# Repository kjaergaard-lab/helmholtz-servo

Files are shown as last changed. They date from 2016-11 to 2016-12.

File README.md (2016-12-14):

# Helmholtz Servo

The design contained here is an analogue PID controller, with some
peculiarities specific for controlling the current though the
Helmholtz coil of our apparatus.

## Status
This project is not yet in production use.

## Where to look

This repository contains the KiCad project for the controller. PDF
copies of the schematic, PCB, and documentation can be found in the
*Generated* folder.

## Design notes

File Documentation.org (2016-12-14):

* Purpose
  This device is intended to be used to regulate the current through a
  Helmholtz coil, used for generating a magnetic field in our cold
  atom collider.

  The majority of the system is built from chopper-stabilized
  amplifiers, for their very low input bias, and DC performance. This
  limits the bandwidth of the filter, and can cause aliasing. Hence
  this controller is not designed for "fast" systems.

  This schematic is for documentation purposes only.

* Signals
Only HH_TTL is isolated, and with the optional exception of the SENSE
input, all other grounds/shields are shared.
** HH_TTL
   The Helmholtz TTL signal switches on or off the output voltage. In
   our case, the control voltage is being used to drive MOSFETs, so
   these are turned off. 
   
   The Integrator is also reset with this signal, preventing accumulation
   while the servo is not active from causing transient behaviour when
   the servo is enabled.

   The polarity of this signal is set by populating certain resistors
   (R9-12, R5, R6) as per the schematic.
   
   This signal is opto-isolated, so may operate at a relative potential
   to the rest of this circuit. The signal is assumed to be 5V, and
   will cause about 10 mA current draw.

** V_REF
   This is the output of a 5 V voltage reference, for use with an
   external DAC.
** V_DAC
   This is assumed to be the output of the DAC, and is used as the
   set-point for the PID controller
** SENSE
   This is the Process Variable, as a current signal. The current
   is passed through a precision 1 ohm resistor, and the resulting
   voltage is compared to V_DAC to generate the error signal.

   The current return is optionally connected to ground by bridging R1.
** OUT
   This is the Control Variable, which is the result of the PID
   operation on the error.

* Configuration
  HH_TTL has selectable polarity by selecting which resistors to
  populate on the analog switches the signal activates. (R9-12, R5,
  R6).

  The SENSE shield can optionally be grounded by putting a 0 ohm
  resistor (or solder bridge) in R1.

  The total polarity of the system is selected using JP1 and
  JP2. These should both be loaded with jumpers between pins 1 and 2
  for the default, non-inverting operation. They should be swapped to
  pins 2 and 3 to invert the output. *NB:* Either remove both jumpers
  first, or make sure device is unpowered with no inputs before
  changing the polarity. This is to ensure that two inputs are not
  shorted together while configuring. Note that during operation, the
  jumpers should be connecting the same pin numbers, but will be
  positioned at physically opposite ends of the jumpers.

* Power
  This board is designed to be powered off a dual supply. If a
  negative supply is not available, the negative supply pin may be grounded,
  and positive operation will be available.

* Erata
** TC7650
   These amplifiers are only capable of a 18 V supply, but the
   specified dual 15 V supplies give supply of 30 V. The circuit can
   be used with +/- 8 V supplies instead of +/- 15 V with these
   amplifiers.

   These amplifiers have been replaced with the LTC1150, which can
   handle these supply ranges, but has a much lower bandwidth. These
   devices were chosen as they are available in a DIP package, and
   could be placed on the existing board, when removing all the
   switching capacitors (C16, C15, C27, C26, C22, C21, C32, C31, C36, C35,
   C40, C41).

** RV6 - Output Gain
   This resistor was wired with pins 1 and 2 reversed in the
   2016-11-14 board. These must be swapped for correct operation.

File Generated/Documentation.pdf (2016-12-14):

### Documentation

December 15, 2016

## Contents

1 Purpose | 1
2 Signals | 2
3 Conguration | 3
4 Power | 3
5 Erata | 3
1 | Purpose

This device is intended to be used to regulate the current through a Helmholtz coil, used for generating a magnetic eld in our cold atom collider.
| The majority of the system is built from chopper-stabilized ampliers, for
their very low input bias, and DC performance. This limits the bandwidth of the lter, and can cause aliasing. Hence this controller is not designed for "fast" systems.
| This schematic is for documentation purposes only.

1

## 2 Signals

Only HHTTL is isolated, and with the optional exception of the SENSE input, all other grounds/shields are shared.

2.1 HHTTL

The Helmholtz TTL signal switches on or o the output voltage. In our case, the control voltage is being used to drive MOSFETs, so these are turned o. The Integrator is also reset with this signal, preventing accumulation while the servo is not active from causing transient behaviour when the servo is enabled.
The polarity of this signal is set by populating certain resistors (R9-12, R5, R6) as per the schematic.
This signal is opto-isolated, so may operate at a relative potential to the rest of this circuit. The signal is assumed to be 5V, and will cause about 10 mA current draw.

2.2 VREF

This is the output of a 5 V voltage reference, for use with an external DAC.

2.3 VDAC

This is assumed to be the output of the DAC, and is used as the set-point for the PID controller

2.4 SENSE

This is the Process Variable, as a current signal. The current is passed through a precision 1 ohm resistor, and the resulting voltage is compared to VDAC to generate the error signal.
The current return is optionally connected to ground by bridging R1.

2.5 OUT

This is the Control Variable, which is the result of the PID operation on the error.

2

## 3 Conguration

HHTTL has selectable polarity by selecting which resistors to populate on the analog switches the signal activates. (R9-12, R5, R6).
The SENSE shield can optionally be grounded by putting a 0 ohm resistor (or solder bridge) in R1.
The total polarity of the system is selected using JP1 and JP2. These should both be loaded with jumpers between pins 1 and 2 for the default, non-inverting operation. They should be swapped to pins 2 and 3 to invert the output. NB: Either remove both jumpers rst, or make sure device is unpowered with no inputs before changing the polarity. This is to ensure that two inputs are not shorted together while conguring. Note that during operation, the jumpers should be connecting the same pin numbers, but will be positioned at physically opposite ends of the jumpers.

## 4 Power

This board is designed to be powered o a dual supply. If a negative supply is not available, the negative supply pin may be grounded, and positive operation will be available.

5 | Erata
5.1 | TC7650

These ampliers are only capable of a 18 V supply, but the specied dual 15 V supplies give supply of 30 V. The circuit can be used with +/- 8 V supplies instead of +/- 15 V with these ampliers.
These ampliers have been replaced with the LTC1150, which can handle these supply ranges, but has a much lower bandwidth. These devices were chosen as they are available in a DIP package, and could be placed on the existing board, when removing all the switching capacitors (C16, C15, C27, C26, C22, C21, C32, C31, C36, C35, C40, C41).

5.2 RV6 - Output Gain

This resistor was wired with pins 1 and 2 reversed in the 2016-11-14 board. These must be swapped for correct operation.

3

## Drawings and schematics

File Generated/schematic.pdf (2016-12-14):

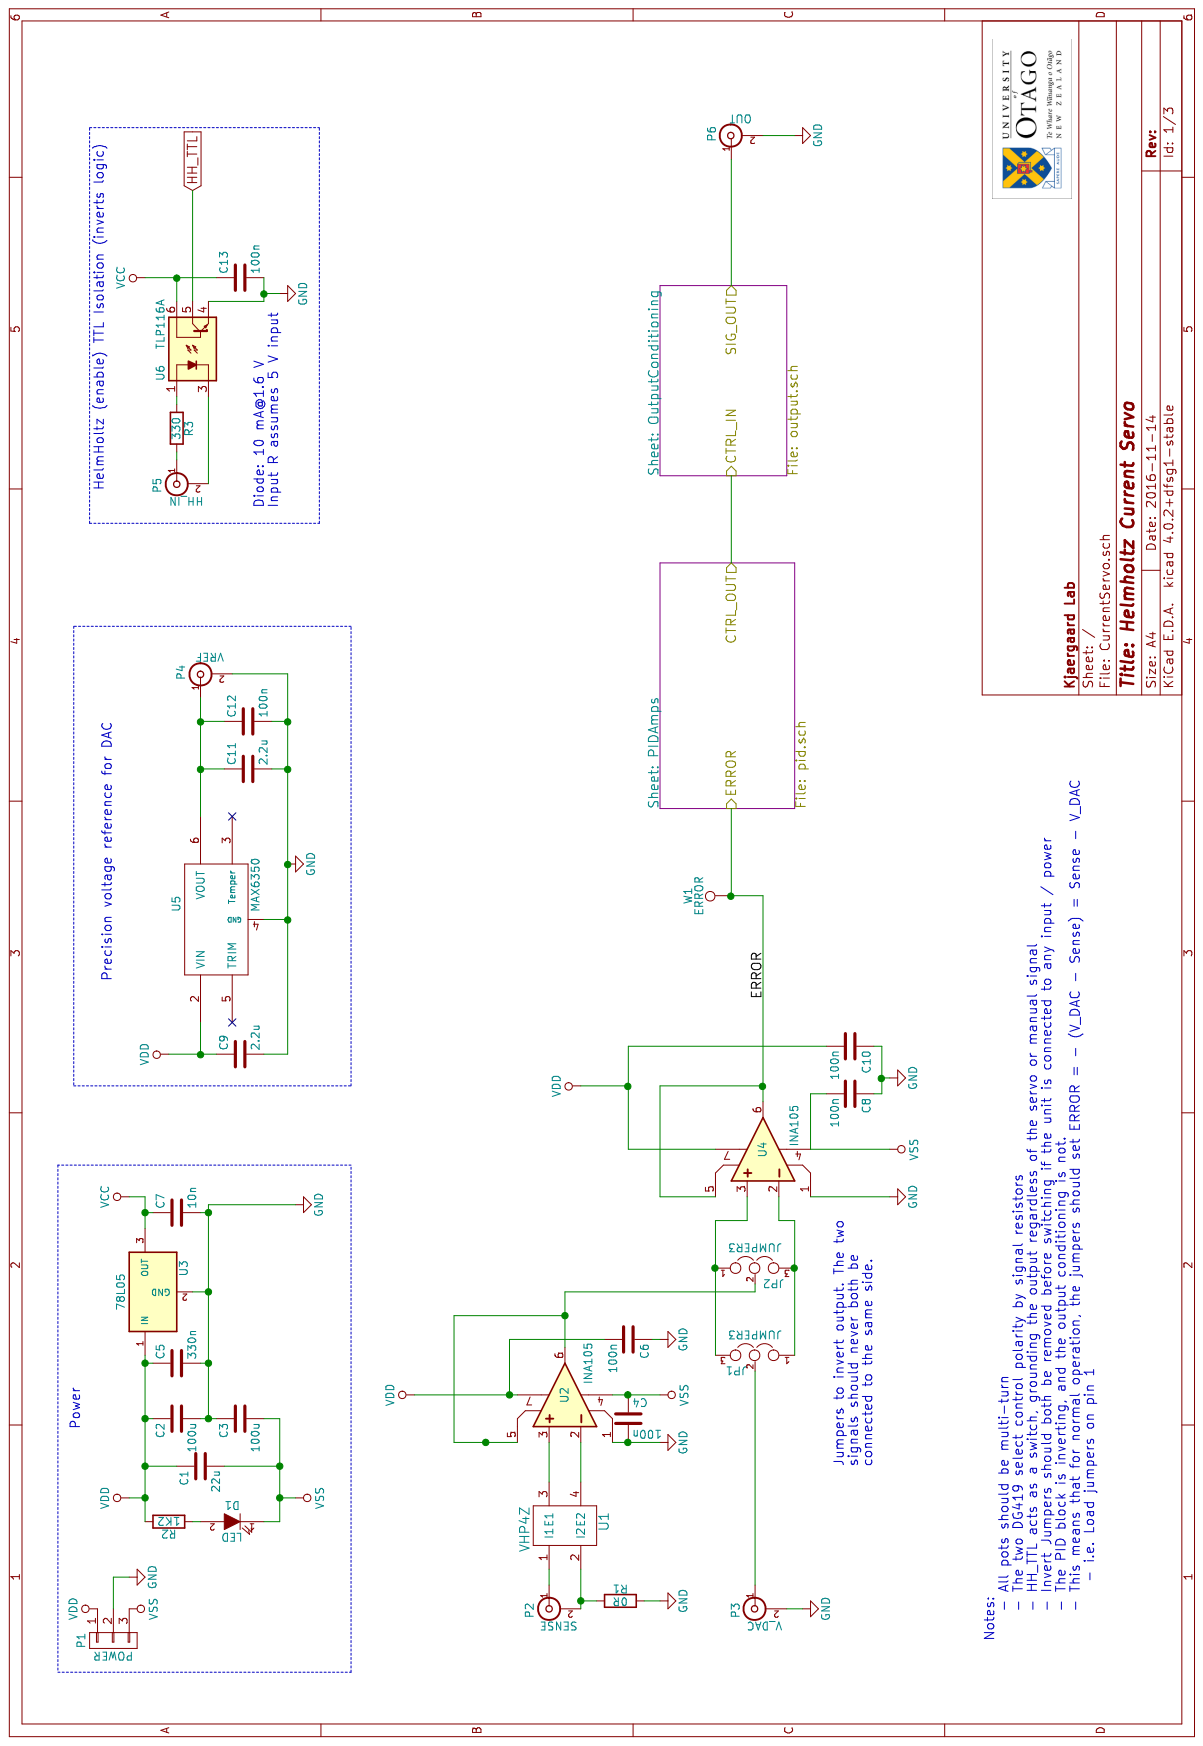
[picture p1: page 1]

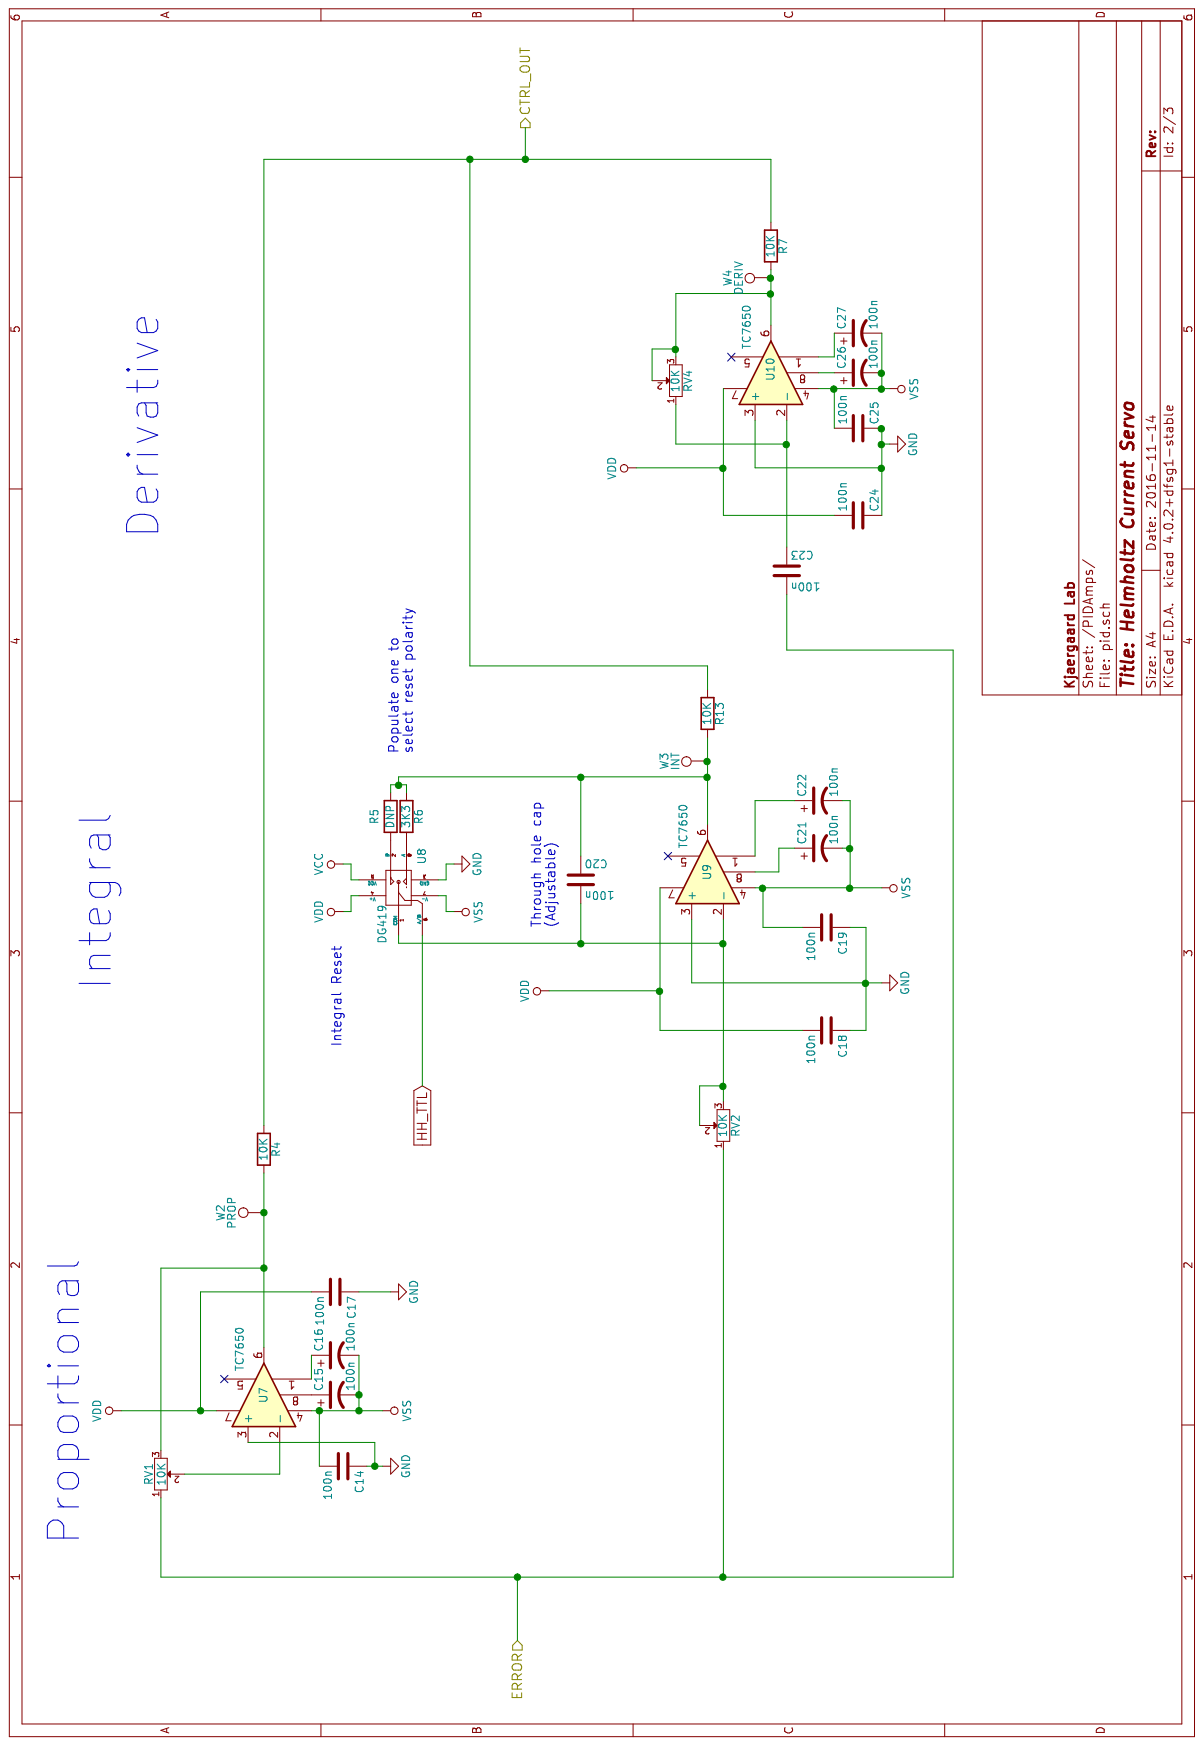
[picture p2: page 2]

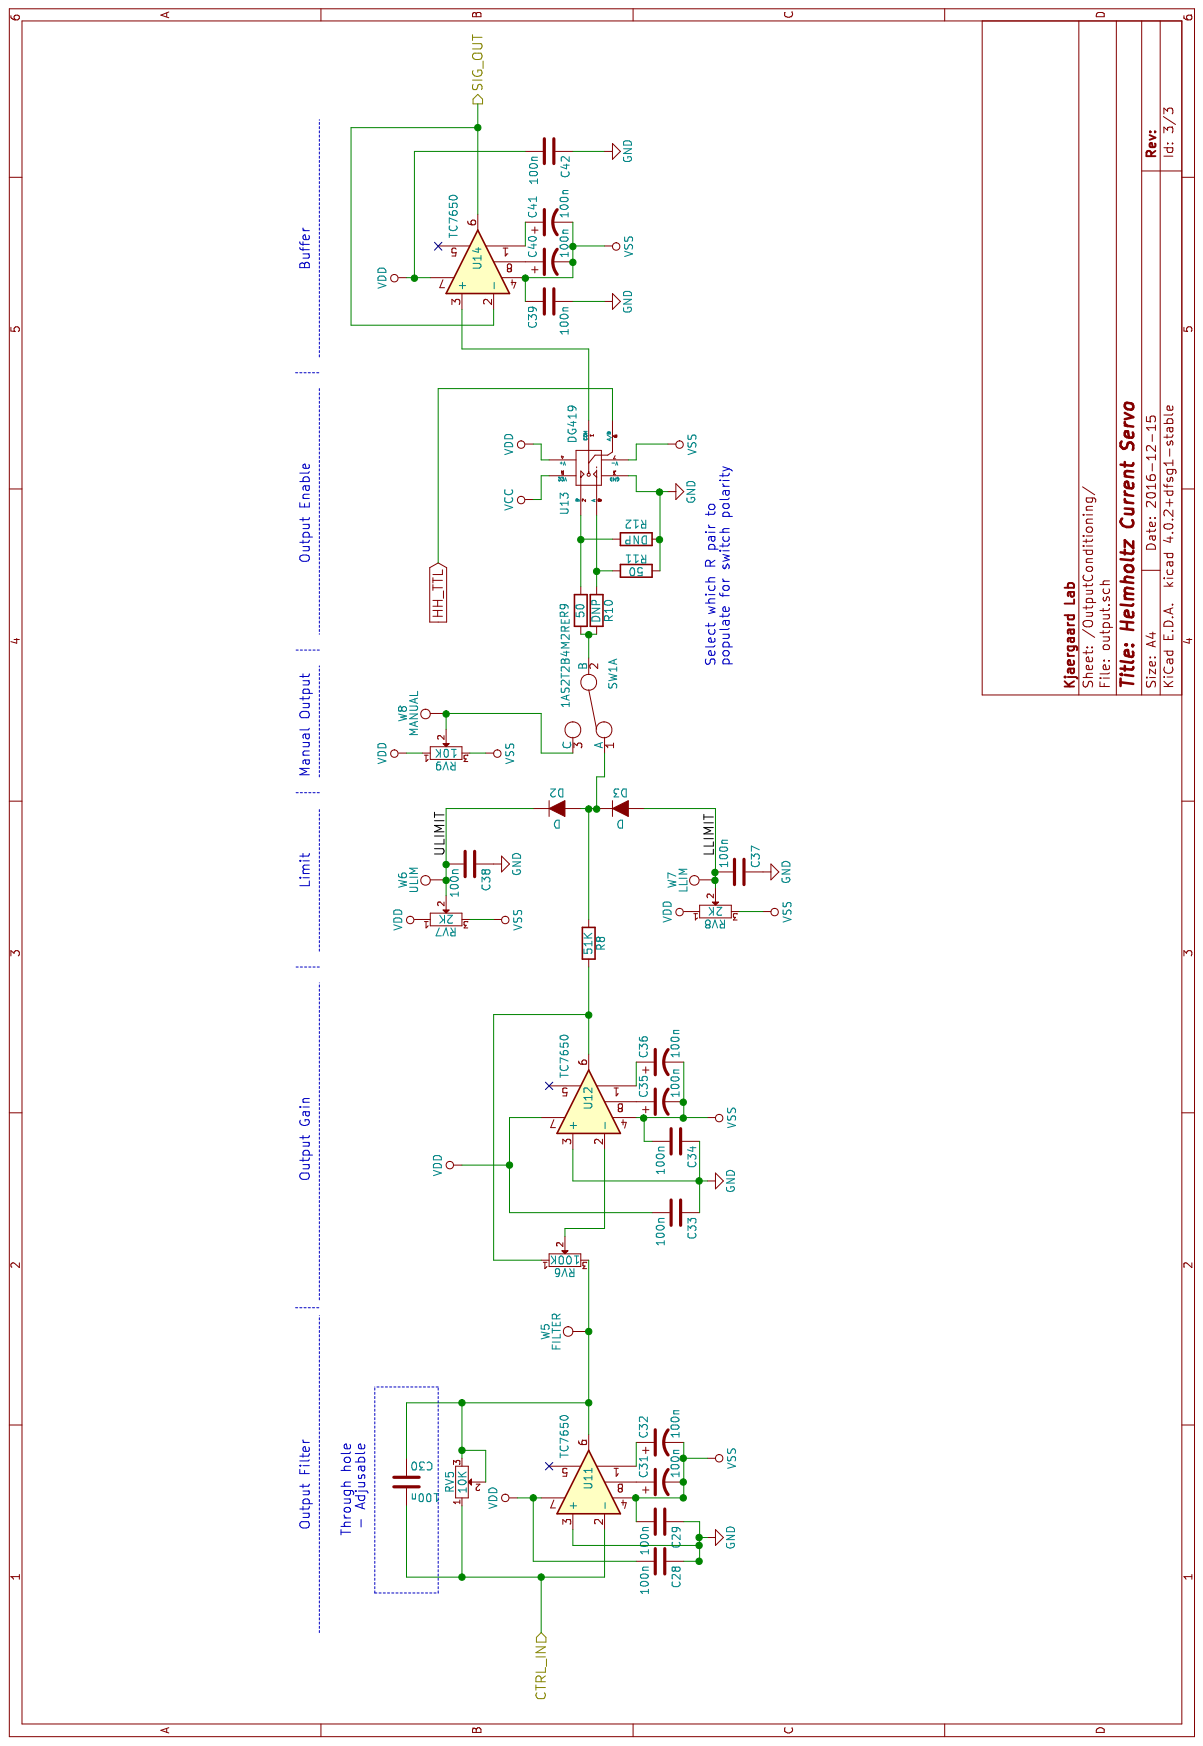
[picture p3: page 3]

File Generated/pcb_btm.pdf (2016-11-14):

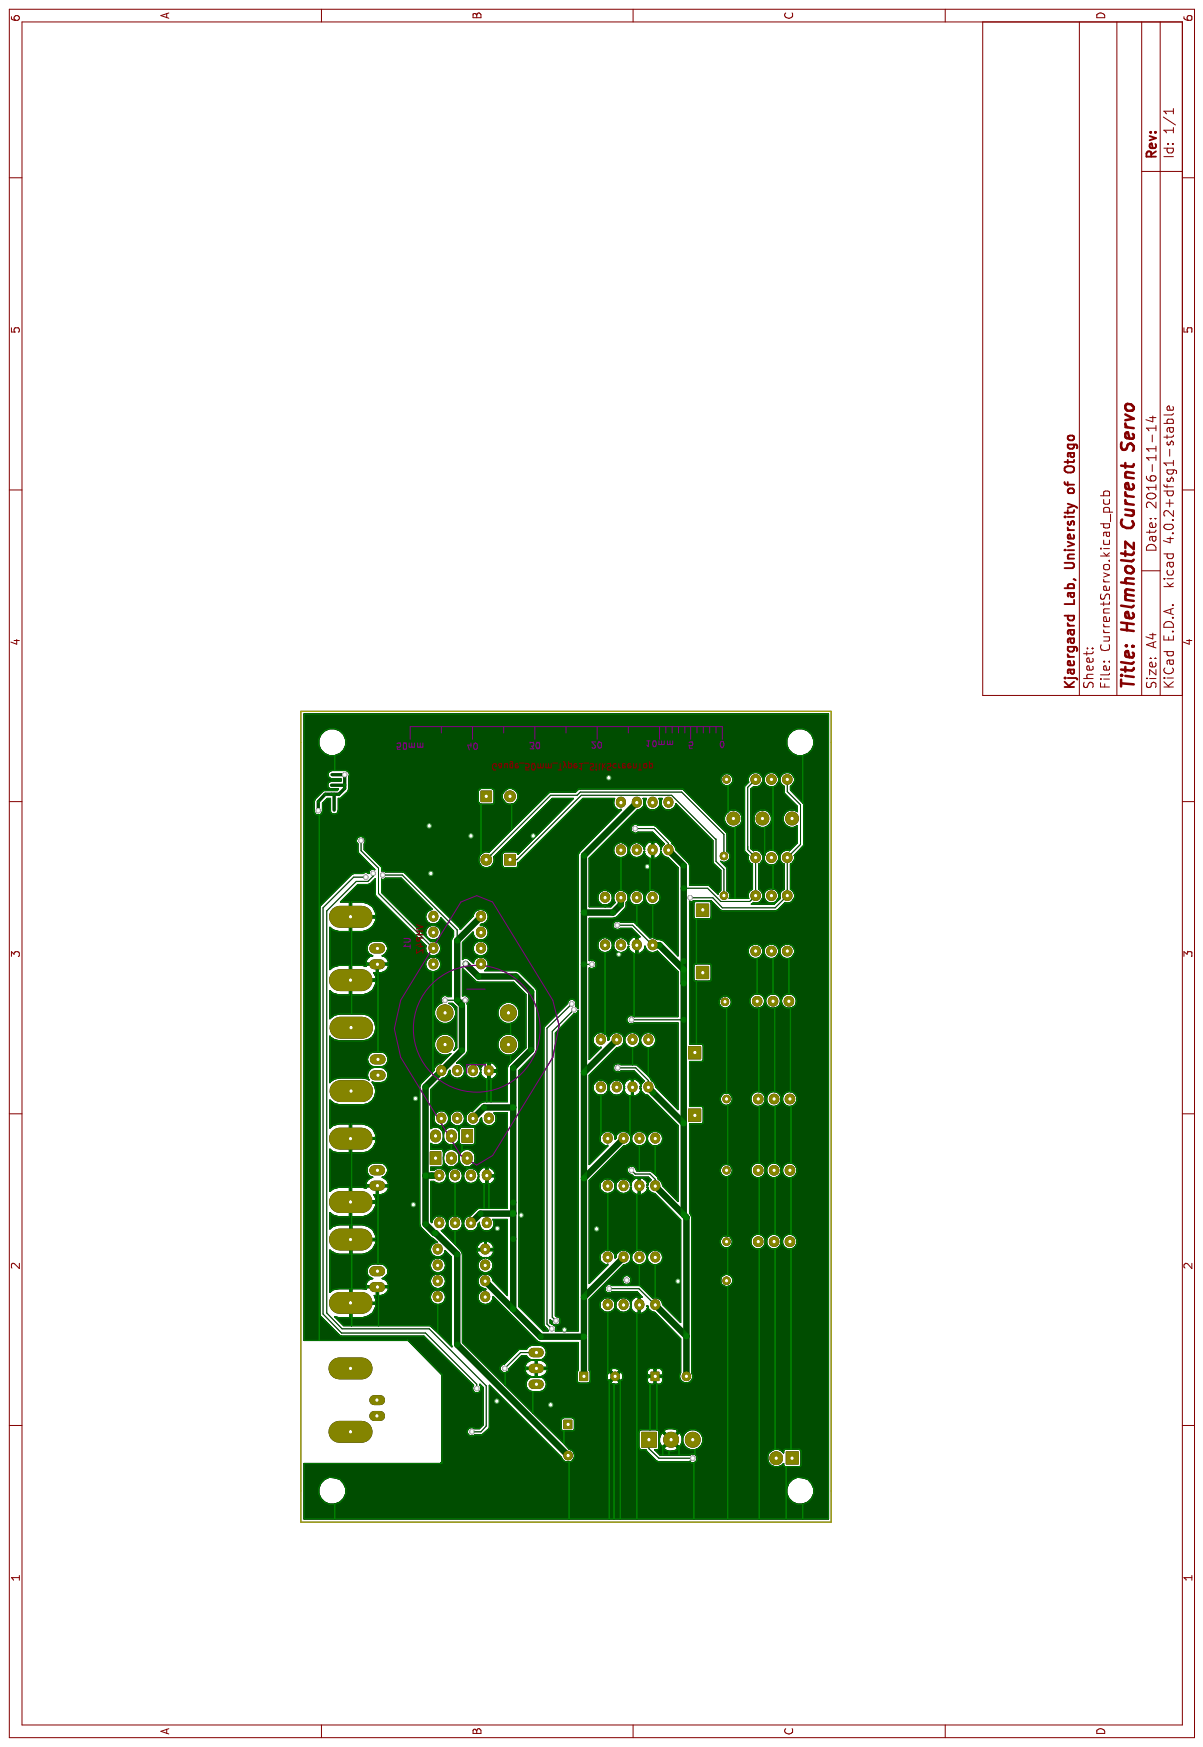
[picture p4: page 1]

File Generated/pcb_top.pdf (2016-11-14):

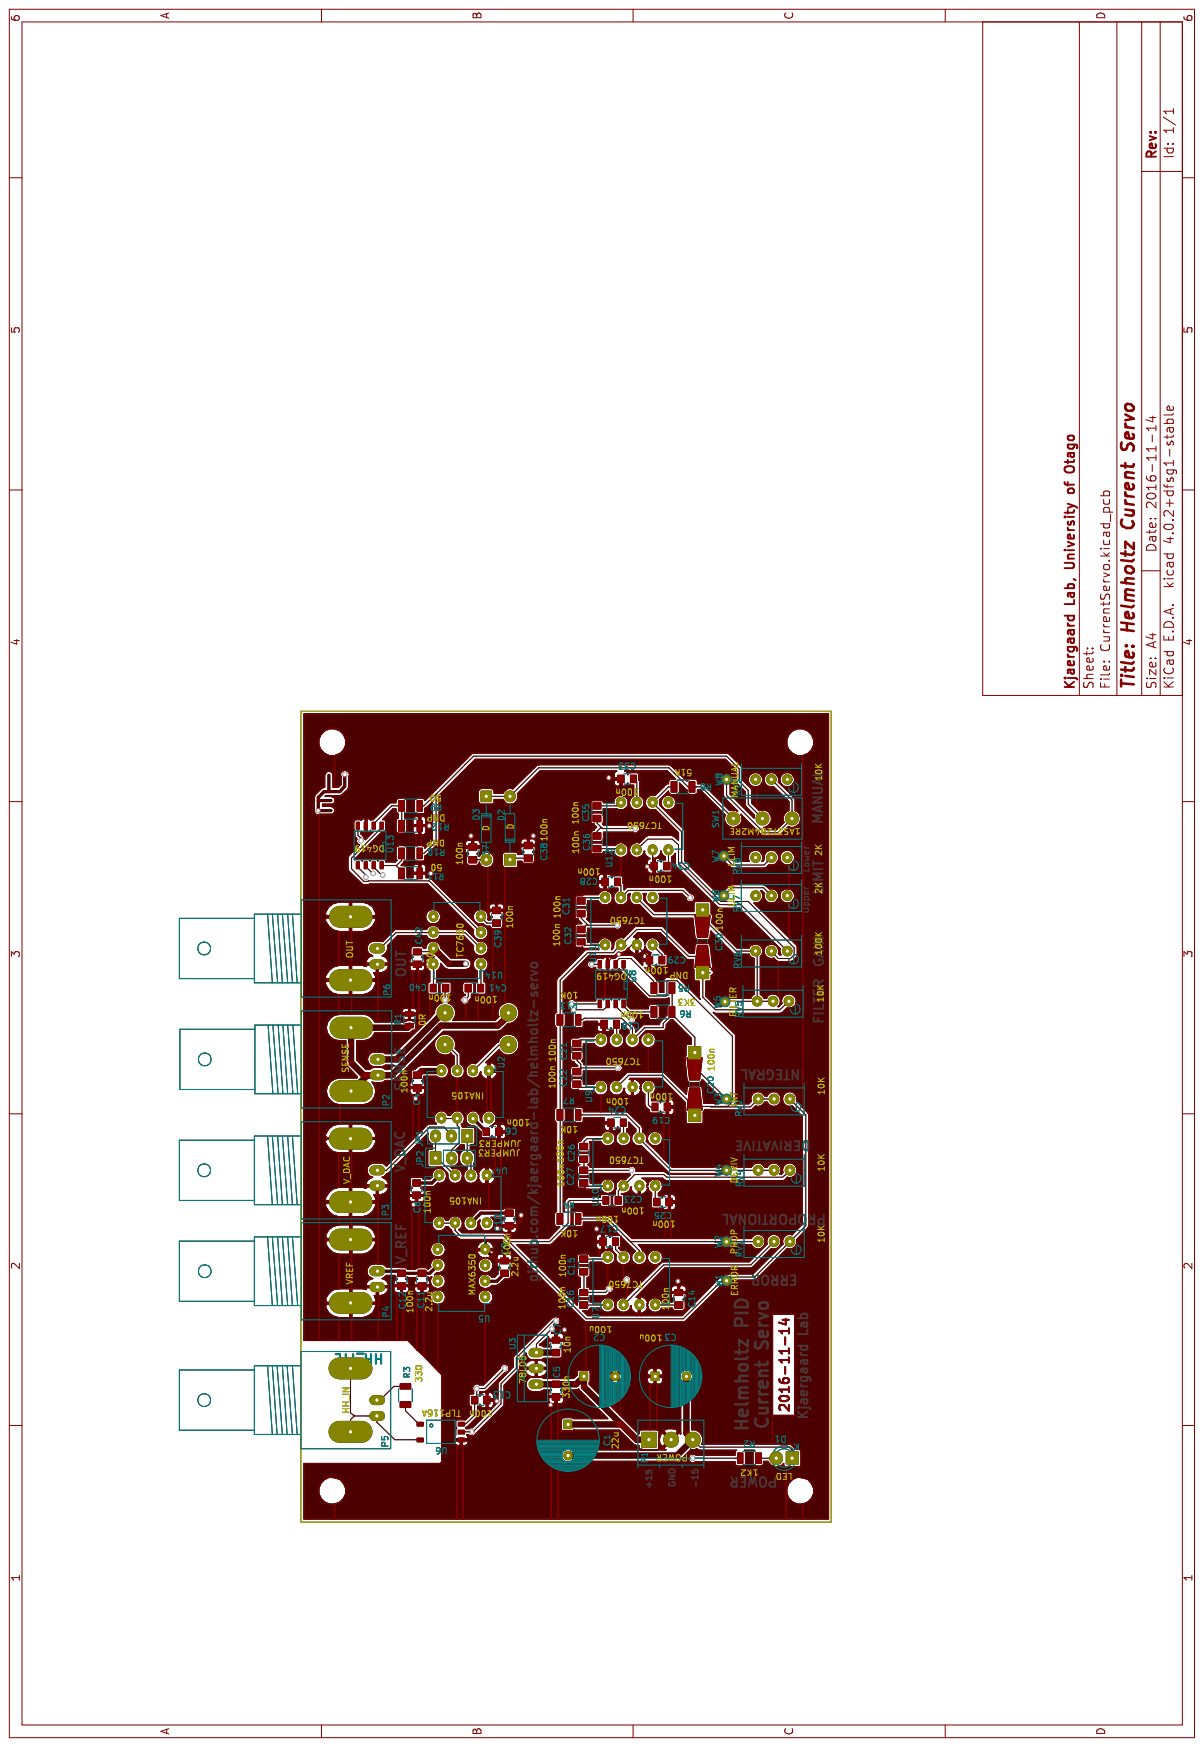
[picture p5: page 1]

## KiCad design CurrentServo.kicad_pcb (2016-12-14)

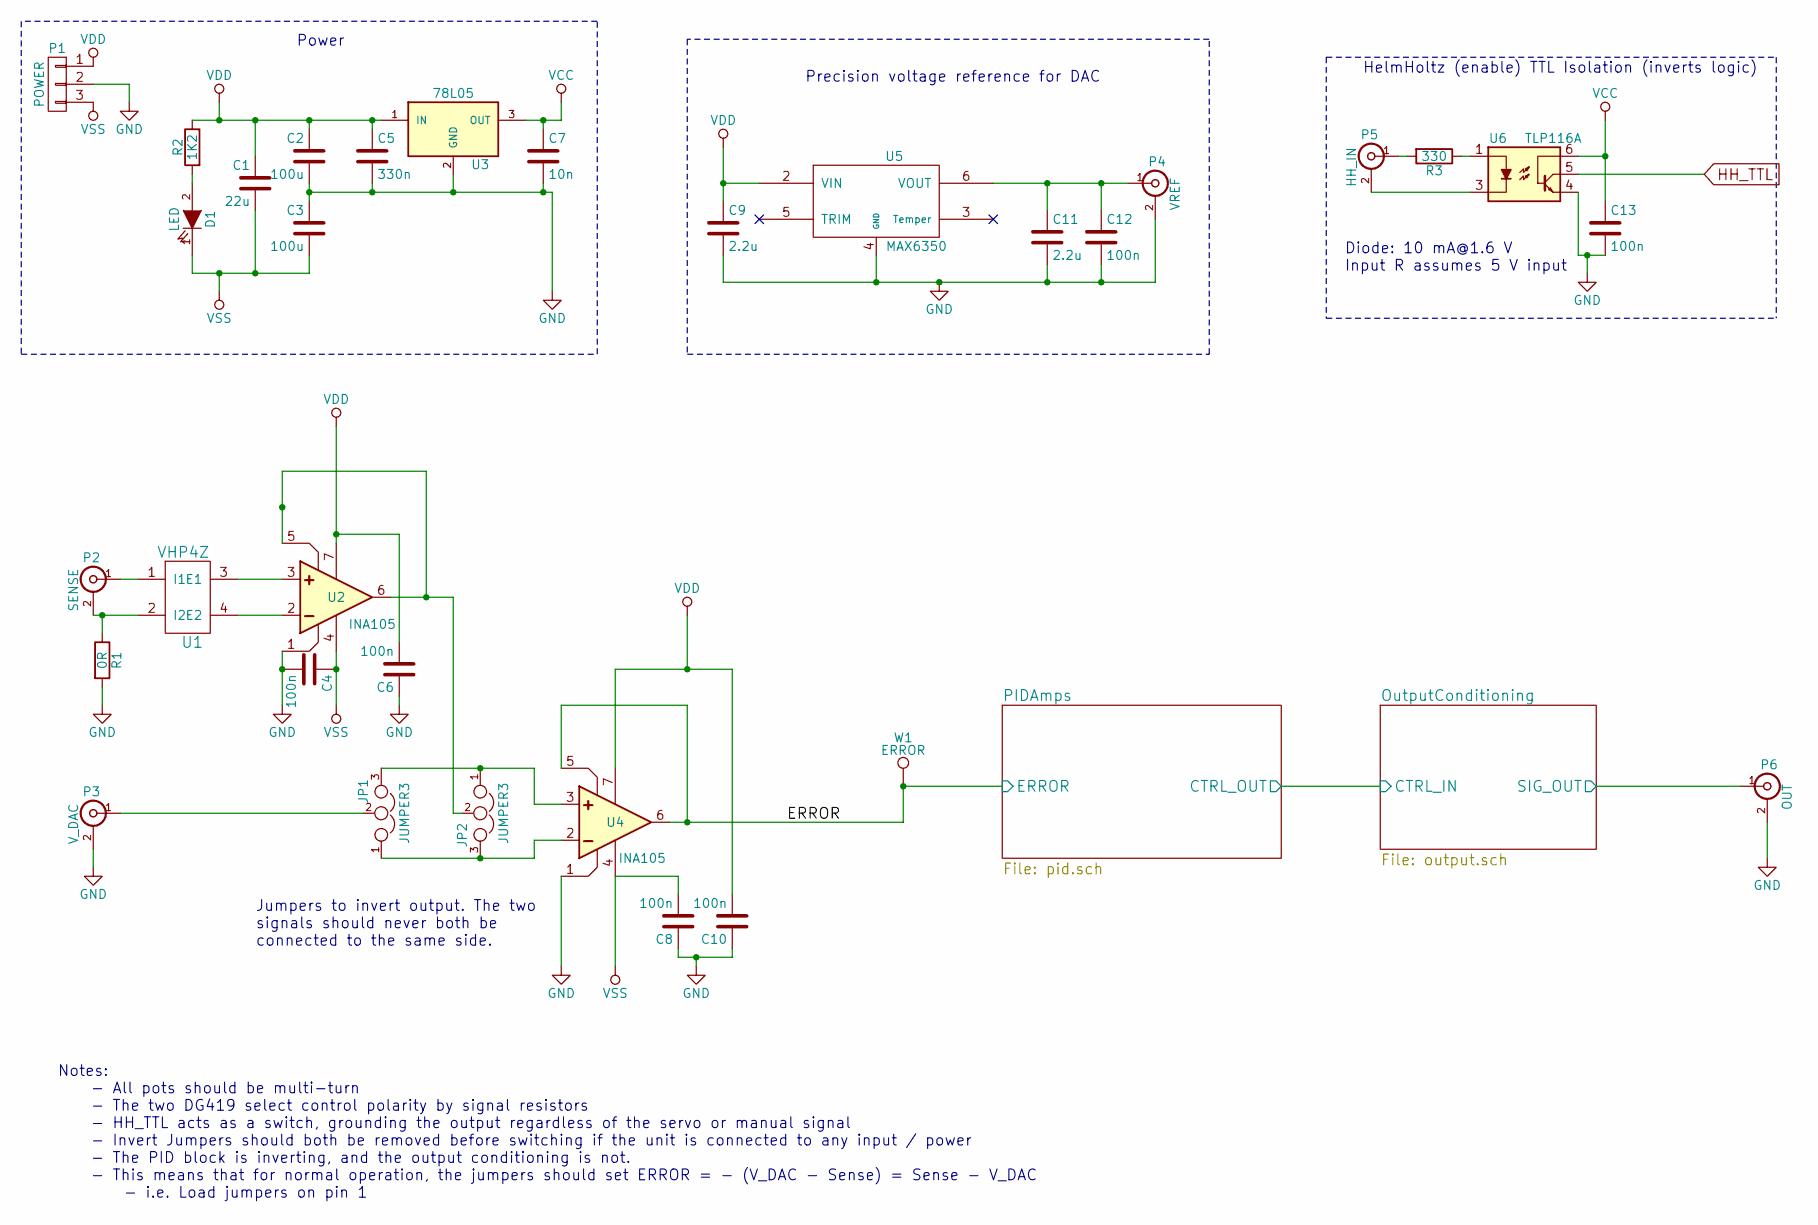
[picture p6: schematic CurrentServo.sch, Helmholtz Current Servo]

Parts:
C1: 22u; C_Radial_D10_L13_P5
C2, C3: 100u; C_Radial_D10_L16_P5
C4, C6, C8, C10, C12, C13: 100n; C_0805
C5: 330n; C_0805
C7: 10n; C_0805
C9, C11: 2.2u; C_0805
D1: LED; LED-3MM
JP1, JP2: JUMPER3; Pin_Header_Straight_1x03
P1: POWER; TerminalBlock_Pheonix_PT-3.5mm_3pol
P2: SENSE; BNC_Socket_TYCO-AMP_LargePads
P3: V_DAC; BNC_Socket_TYCO-AMP_LargePads
P4: VREF; BNC_Socket_TYCO-AMP_LargePads
P5: HH_IN; BNC_Socket_TYCO-AMP_LargePads
P6: OUT; BNC_Socket_TYCO-AMP_LargePads
R1: 0R; R_0805
R2: 1K2; R_1206
R3: 330; R_1206
U1: VHP4Z
U2, U4: INA105; DIP-8_W7.62mm
U3: 78L05; TO-220_Neutral123_Vertical
U5: MAX6350; DIP-8_W7.62mm
U6: TLP116A
W1: ERROR; PINTST

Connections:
/OutputConditioning/SIG_OUT: P6.1 (In); also elsewhere on the board
/PIDAmps/ERROR: U4.5 (BALANCE), U4.6 (OUTPUT), W1.1; also elsewhere on the board
GND: C2.2, C3.1, C4.2, C5.2, C6.1, C7.2, C8.1, C9.2, C10.1, C11.2, C12.2, C13.2, P1.2, P3.2 (Ext), P4.2 (Ext), P6.2 (Ext), R1.2, U2.1 (BAL/COMP), U3.2 (GND), U4.1 (BAL/COMP), U5.4 (GND), U6.4; also elsewhere on the board
HH_TTL: U6.5; also elsewhere on the board
unnamed: C11.1, C12.1, P4.1 (In), U5.6 (VOUT)
unnamed: D1.2 (A), R2.2
unnamed: JP1.1, JP2.3, U4.2 (INVERTING)
unnamed: JP1.2, P3.1 (In)
unnamed: JP1.3, JP2.1, U4.3 (NON)
unnamed: JP2.2, U2.5 (BALANCE), U2.6 (OUTPUT)
unnamed: P2.1 (In), U1.1 (I1)
unnamed: P2.2 (Ext), R1.1, U1.2 (I2)
unnamed: P5.1 (In), R3.2
unnamed: P5.2 (Ext), U6.3
unnamed: R3.1, U6.1
unnamed: U1.3 (E1), U2.3 (NON)
unnamed: U1.4 (E2), U2.2 (INVERTING)
VCC: C7.1, C13.1, U3.3 (OUT), U6.6; also elsewhere on the board
VDD: C1.1, C2.1, C5.1, C6.2, C9.1, C10.2, P1.1, R2.1, U2.7 (V+), U3.1 (IN), U4.7 (V+), U5.2 (VIN); also elsewhere on the board
VSS: C1.2, C3.2, C4.1, C8.2, D1.1 (K), P1.3, U2.4 (V-), U4.4 (V-); also elsewhere on the board

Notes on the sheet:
Power
HelmHoltz (enable) TTL Isolation (inverts logic)
Precision voltage reference for DAC
Diode: 10 mA@1.6 V Input R assumes 5 V input
Notes: - All pots should be multi-turn - The two DG419 select control polarity by signal resistors - HH_TTL acts as a switch, grounding the output regardless of the servo or manual signal - Invert Jumpers should both be removed before switching if the unit is connected to any input / power - The PI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
Jumpers to invert output. The two signals should never both be connected to the same side.

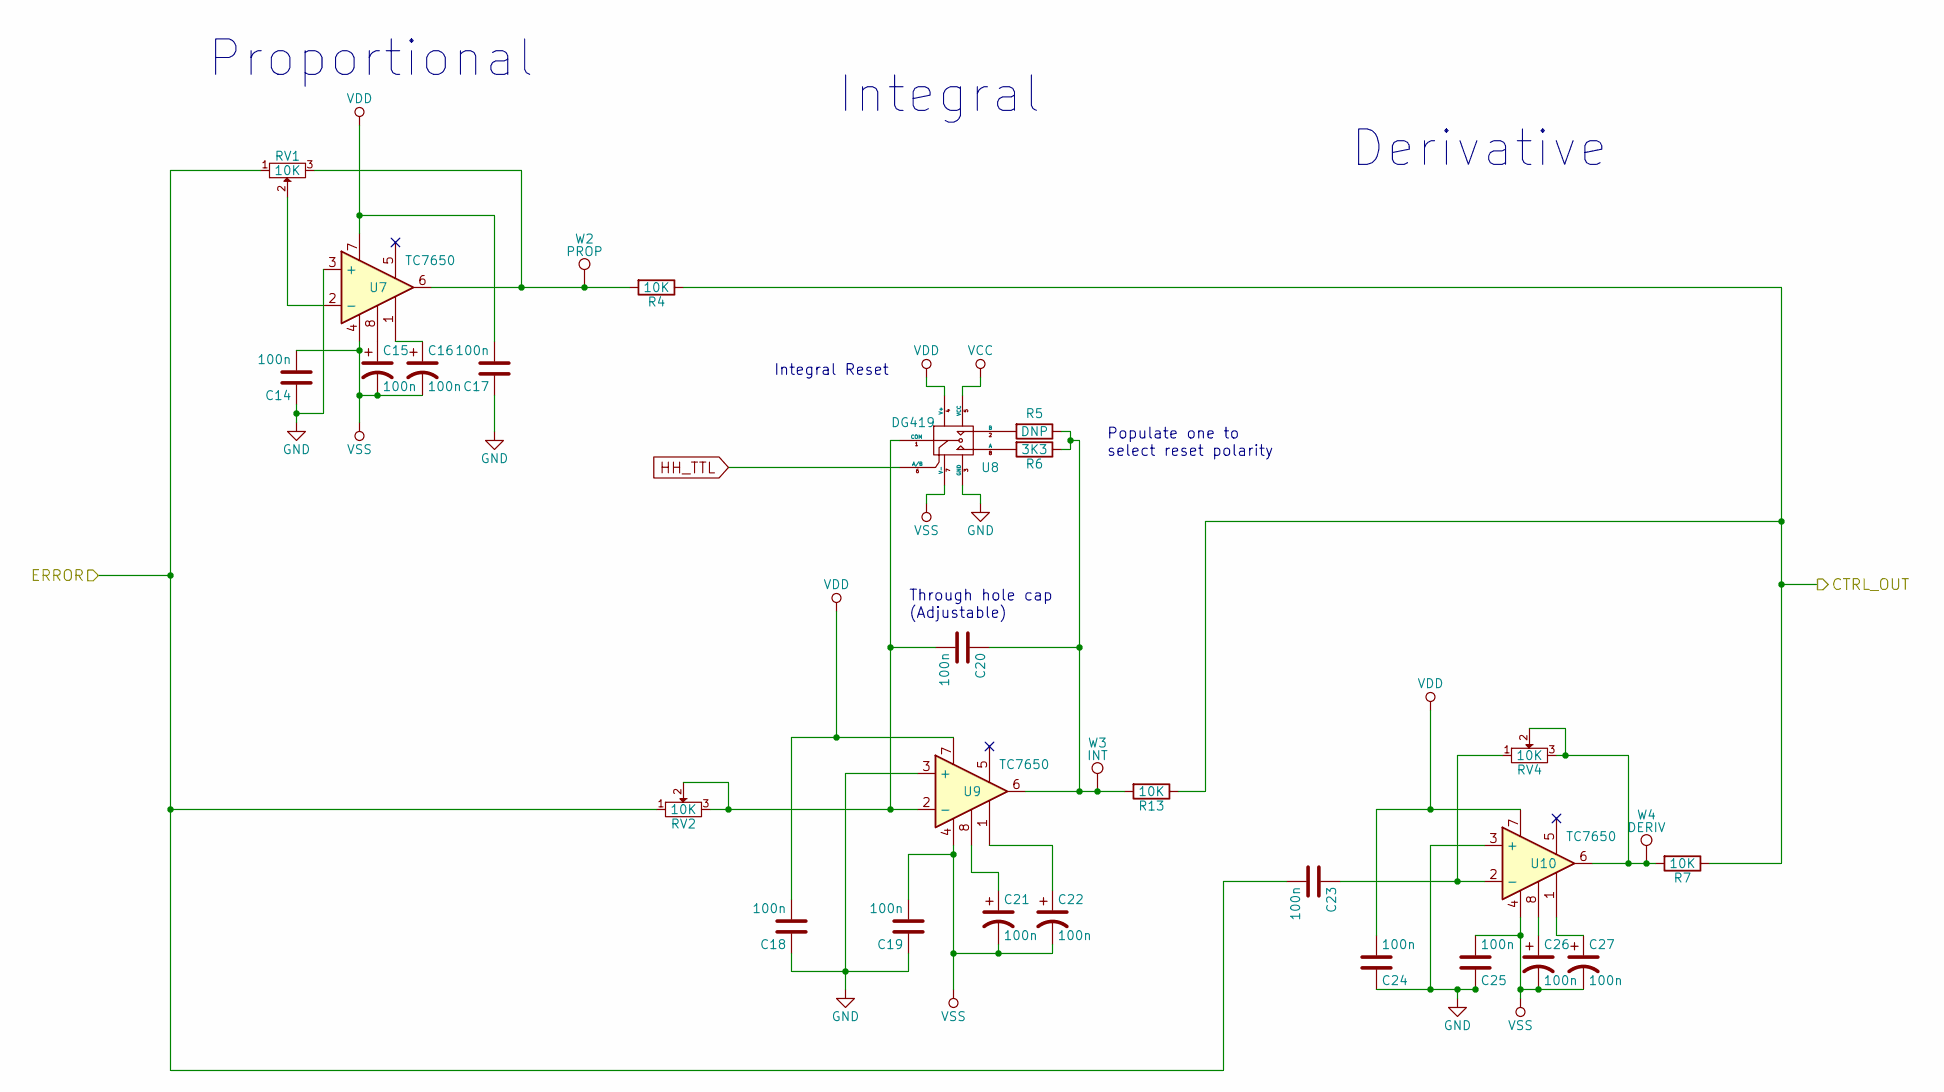
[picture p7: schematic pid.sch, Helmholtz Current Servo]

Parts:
C14, C15, C16, C17, C18, C19, C21, C22, C23, C24, C25, C26, C27: 100n; C_0805
C20: 100n; Resistor_SMD+THTuniversal_0805to1206_RM10_HandSoldering
R4, R7, R13: 10K; R_1206
R5: DNP; R_1206
R6: 3K3; R_1206
RV1, RV2, RV4: 10K; Potentiometer_Bourns_3296W_3-8Zoll_Inline_ScrewUp
U7, U9, U10: TC7650; DIP-8_W7.62mm
U8: DG419; SOIC-8-N
W2: PROP; PINTST
W3: INT; PINTST
W4: DERIV; PINTST

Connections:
/OutputConditioning/CTRL_IN: R4.1, R7.1, R13.1; also elsewhere on the board
/PIDAmps/ERROR: C23.2, RV1.1, RV2.1; also elsewhere on the board
GND: C14.1, C17.1, C18.1, C19.1, C24.1, C25.1, U7.3 (+), U8.3 (GND), U9.3 (+), U10.3 (+); also elsewhere on the board
HH_TTL: U8.6 (A/B); also elsewhere on the board
unnamed: C15.1, U7.8
unnamed: C16.1, U7.1
unnamed: C20.1, R5.1, R6.1, R13.2, U9.6, W3.1
unnamed: C20.2, RV2.2, RV2.3, U8.1 (COM), U9.2 (-)
unnamed: C21.1, U9.8
unnamed: C22.1, U9.1
unnamed: C23.1, RV4.1, U10.2 (-)
unnamed: C26.1, U10.8
unnamed: C27.1, U10.1
unnamed: R4.2, RV1.3, U7.6, W2.1
unnamed: R5.2, U8.2 (B)
unnamed: R6.2, U8.8 (A)
unnamed: R7.2, RV4.2, RV4.3, U10.6, W4.1
unnamed: RV1.2, U7.2 (-)
VCC: U8.5 (VCC); also elsewhere on the board
VDD: C17.2, C18.2, C24.2, U7.7, U8.4 (V+), U9.7, U10.7; also elsewhere on the board
VSS: C14.2, C15.2, C16.2, C19.2, C21.2, C22.2, C25.2, C26.2, C27.2, U7.4, U8.7 (V-), U9.4, U10.4; also elsewhere on the board

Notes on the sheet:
Through hole cap (Adjustable)
Proportional
Derivative
Integral
Populate one to select reset polarity
Integral Reset

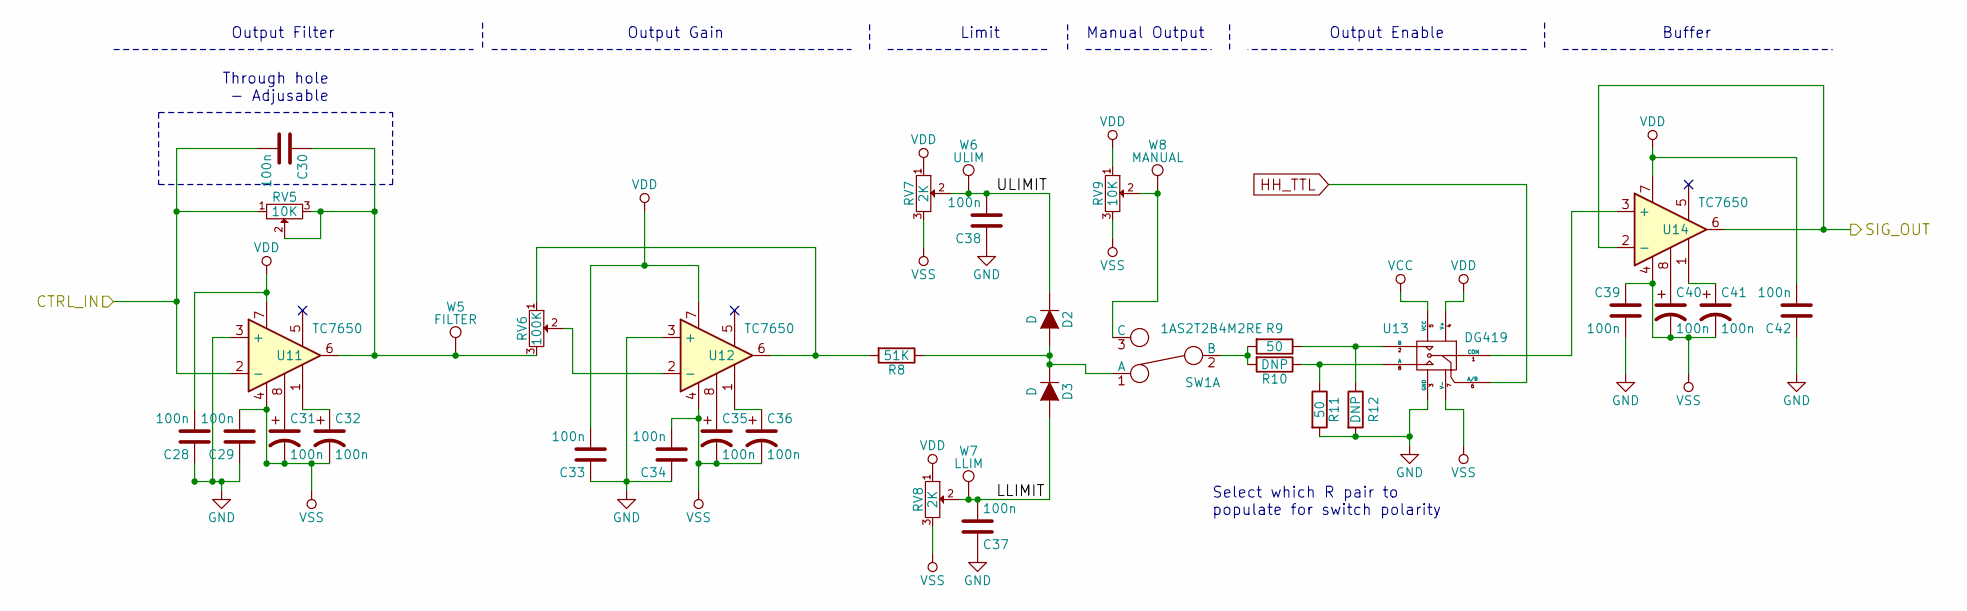
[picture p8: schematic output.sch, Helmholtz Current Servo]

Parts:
C28, C29, C31, C32, C33, C34, C35, C36, C37, C38, C39, C40, C41, C42: 100n; C_0805
C30: 100n; Resistor_SMD+THTuniversal_0805to1206_RM10_HandSoldering
D2, D3: D; Diode_DO-35_SOD27_Horizontal_RM10
R8: 51K; R_1206
R9, R11: 50; R_1206
R10, R12: DNP; R_1206
RV5, RV9: 10K; Potentiometer_Bourns_3296W_3-8Zoll_Inline_ScrewUp
RV6: 100K; Potentiometer_Bourns_3296W_3-8Zoll_Inline_ScrewUp
RV7, RV8: 2K; Potentiometer_Bourns_3296W_3-8Zoll_Inline_ScrewUp
SW1: 1AS2T2B4M2RE; Switch_SPDT_4.7mm
U11, U12, U14: TC7650; DIP-8_W7.62mm
U13: DG419; SOIC-8-N
W5: FILTER; PINTST
W6: ULIM; PINTST
W7: LLIM; PINTST
W8: MANUAL; PINTST

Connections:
/OutputConditioning/CTRL_IN: C30.2, RV5.1, U11.2 (-); also elsewhere on the board
/OutputConditioning/LLIMIT: C37.2, D3.2 (A), RV8.2, W7.1
/OutputConditioning/SIG_OUT: U14.2 (-), U14.6; also elsewhere on the board
/OutputConditioning/ULIMIT: C38.2, D2.1 (K), RV7.2, W6.1
GND: C28.1, C29.1, C33.1, C34.1, C37.1, C38.1, C39.2, C42.1, R11.2, R12.2, U11.3 (+), U12.3 (+), U13.3 (GND); also elsewhere on the board
HH_TTL: U13.6 (A/B); also elsewhere on the board
unnamed: C30.1, RV5.2, RV5.3, RV6.3, U11.6, W5.1
unnamed: C31.1, U11.8
unnamed: C32.1, U11.1
unnamed: C35.1, U12.8
unnamed: C36.1, U12.1
unnamed: C40.1, U14.8
unnamed: C41.1, U14.1
unnamed: D2.2 (A), D3.1 (K), R8.1, SW1.1 (A)
unnamed: R8.2, RV6.1, U12.6
unnamed: R10.1, R11.1, U13.8 (A)
unnamed: R9.2, R10.2, SW1.2 (B)
unnamed: R9.1, R12.1, U13.2 (B)
unnamed: RV6.2, U12.2 (-)
unnamed: RV9.2, SW1.3 (C), W8.1
unnamed: U13.1 (COM), U14.3 (+)
VCC: U13.5 (VCC); also elsewhere on the board
VDD: C28.2, C33.2, C42.2, RV7.1, RV8.1, RV9.1, U11.7, U12.7, U13.4 (V+), U14.7; also elsewhere on the board
VSS: C29.2, C31.2, C32.2, C34.2, C35.2, C36.2, C39.1, C40.2, C41.2, RV7.3, RV8.3, RV9.3, U11.4, U12.4, U13.7 (V-), U14.4; also elsewhere on the board

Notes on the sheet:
Through hole - Adjusable
Limit
Output Enable
Buffer
Output Gain
Output Filter
Select which R pair to populate for switch polarity
Manual Output

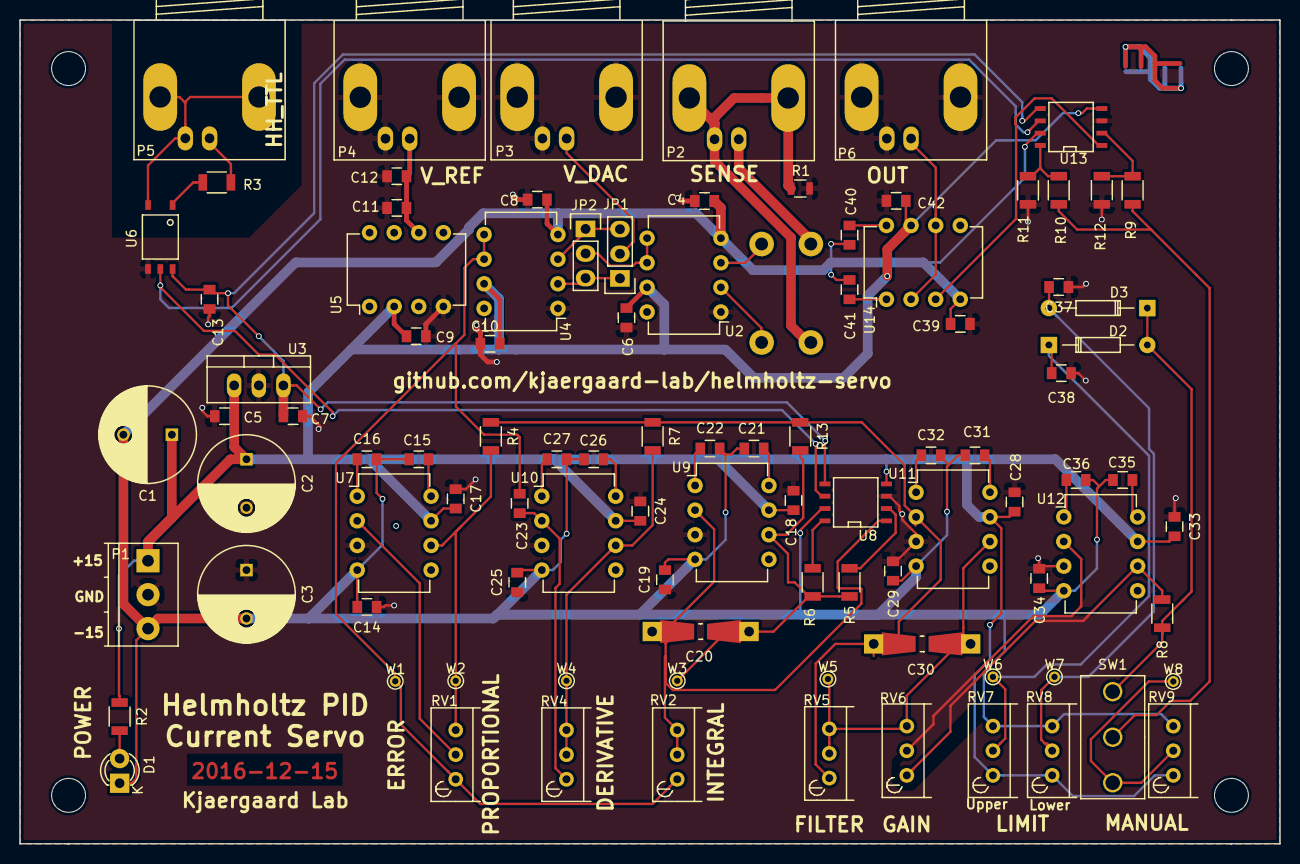
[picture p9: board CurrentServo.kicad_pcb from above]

Board: 2 copper layers, 130.0 x 85.0 mm, 97 parts (1 on the bottom side), 52 nets.

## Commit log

2016-11-10 First revision design
    [CurrentServo.kicad_pcb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]
2016-11-14 Files sent for manufacture
    [CurrentServo-B.Cu.gbr, CurrentServo-B.Mask.gbr, CurrentServo-B.SilkS.gbr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]
2016-12-14 Documented and fixed output gain bug
    [CurrentServo.kicad_pcb, output.sch]
